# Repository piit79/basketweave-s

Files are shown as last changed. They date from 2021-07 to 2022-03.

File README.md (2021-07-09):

# Basketweave-S

Through-hole Alice-style keyboard with arrow keys, symmetric 3-key macro clusters, and a rotary encoder

Based on the [Basketweave](https://github.com/null-l/basketweave) by [null-l](https://github.com/null-l)

### Default Layout
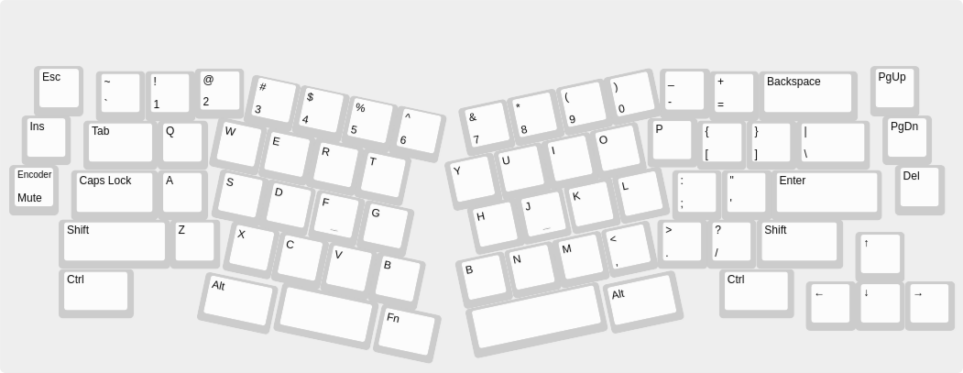
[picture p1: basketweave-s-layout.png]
Default Layout

> View on [Keyboard Layout Editor](http://www.keyboard-layout-editor.com/#/gists/975ace00974ba7fb16d758d6a68e5321)

### BOM and Build Guide
[Build Guide](doc/build.md)

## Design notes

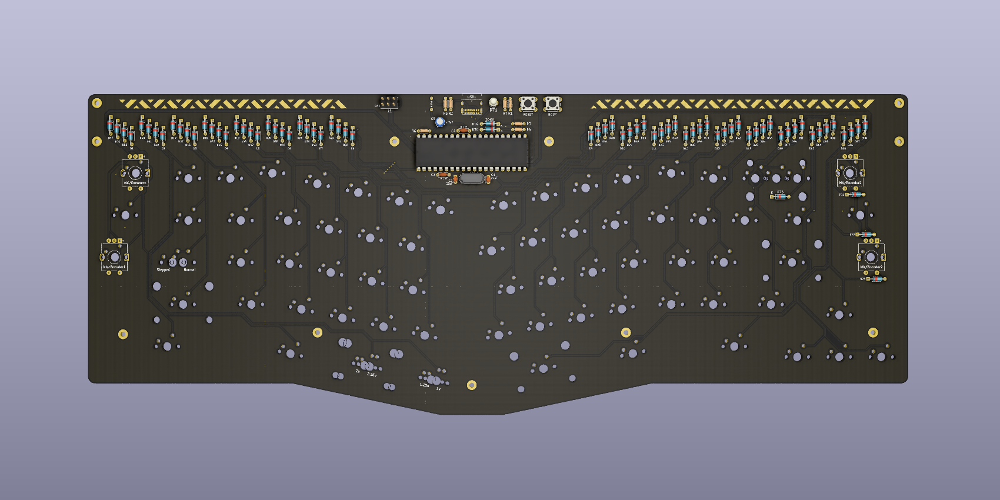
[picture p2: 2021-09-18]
basketweave/basketweave-s-1.9-pcb.png

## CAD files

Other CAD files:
basketweave/basketweave-acrylic-cover.dxf

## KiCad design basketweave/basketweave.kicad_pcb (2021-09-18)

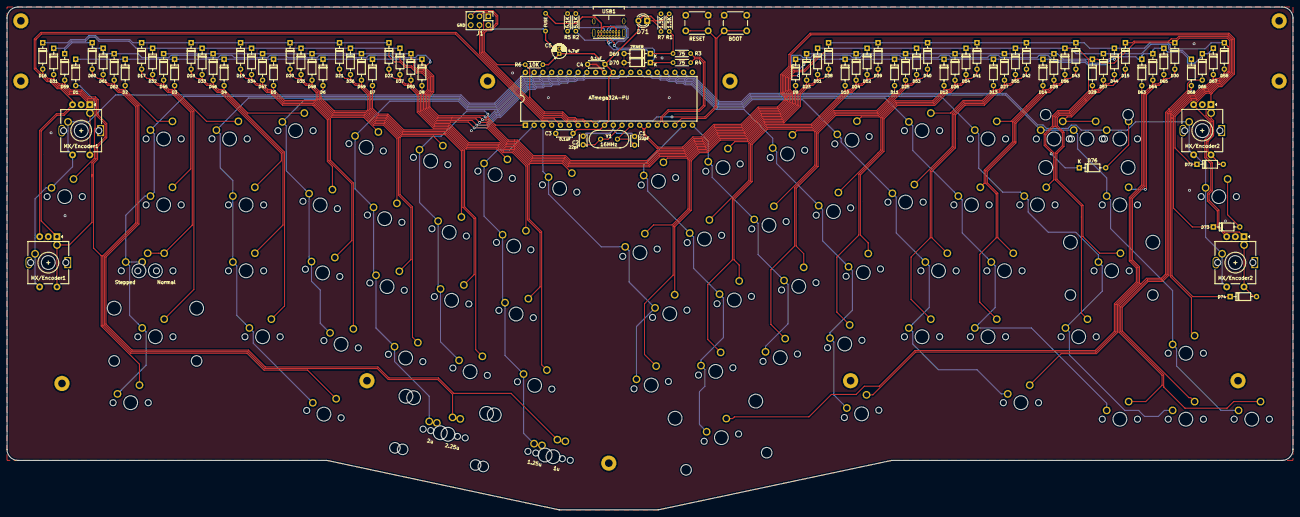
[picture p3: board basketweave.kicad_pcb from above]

Board: 2 copper layers, 371.5 x 145.3 mm, 187 parts (0 on the bottom side), 114 nets.

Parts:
C1, C2: 22pF; C_Disc_D3.0mm_W2.0mm_P2.50mm
C3, C4: 0.1uF; C_Disc_D4.3mm_W1.9mm_P5.00mm
C5: 4.7uF; CP_Radial_D4.0mm_P1.50mm
D1, D2, D3, D4, D5, D6, D7, D8, D9, D10, D11, D12, D13, D14, D15, D16, D17, D18, D19, D20, D21, D22, D23, D24, D25, D26, D27, D28, D29, D30, D31, D32, D33, D34, D35, D36, D37, D38, D39, D40, D41, D42, D43, D44, D45, D46, D47, D48, D49, D50, D51, D52, D53, D54, D55, D56, D57, D58, D59, D60, D61, D62, D63, D64, D65, D66, D67, D68, D72, D73, D74, D76: D_Small; D_DO-35_SOD27_P7.62mm_Horizontal
D69, D70: 3.6V; D_DO-35_SOD27_P7.62mm_Horizontal
D71: LED; LED_D3.0mm_Clear
F1: 500mA; polyfuse_5.1mm
H1, H2, H3, H4, H5, H6, H7, H8, H9, H11, H13: MountingHole; MountingHole_2.2mm_M2_Pad
J1: AVR-ISP-6; PinHeader_2x03_P2.54mm_Vertical
MX1, MX2, MX3, MX4, MX5, MX6, MX7, MX8, MX9, MX10, MX11, MX12, MX13, MX14, MX16, MX18, MX19, MX20, MX21, MX22, MX23, MX24, MX25, MX26, MX27, MX28, MX29, MX31, MX34, MX35, MX36, MX37, MX38, MX39, MX40, MX41, MX42, MX43, MX44, MX47, MX48, MX49, MX50, MX51, MX52, MX53, MX54, MX55, MX56, MX57, MX59, MX67, MX68, MX69, MX71, MX72, MX73, MX74, MX75, MX76: MX-NoLED; MXOnly-1U-NoLED
MX15: MX-NoLED; MXOnly-2U-NoLED
MX17, MX30, MX60, MX61, MX65, MX66: MX-NoLED; MXOnly-1.5U-NoLED
MX32, MX63: MX-NoLED; MXOnly-1.25U-NoLED
MX33, MX58: MX-NoLED; MXOnly-1.75U-NoLED
MX45, MX46, MX70: MX-NoLED; MXOnly-2.25U-ReversedStabilizers-NoLED
MX62: MX-NoLED; MXOnly-2U-ReversedStabilizers-NoLED
MX64: MX-NoLED; MXOnly-2.75U-ReversedStabilizers-NoLED
PATTERN1: Pattern_Left; pattern_left
PATTERN2: Pattern_Right; pattern_right
R1, R7: 1.5K; R_Axial_DIN0204_L3.6mm_D1.6mm_P5.08mm_Horizontal
R2, R5: 5.1K; R_Axial_DIN0204_L3.6mm_D1.6mm_P5.08mm_Horizontal
R3, R4: 75; R_Axial_DIN0204_L3.6mm_D1.6mm_P5.08mm_Horizontal
R6: 10K; R_Axial_DIN0204_L3.6mm_D1.6mm_P5.08mm_Horizontal
SW1: BOOT; SW_PUSH_6mm
SW2: RESET; SW_PUSH_6mm
SW3, SW4, SW5, SW6: Rotary_Encoder_Switch; RotaryEncoder_Alps_EC11E-Switch_Vertical_H20mm-for-MX
U1: ATmega32A-PU; DIP-40_W15.24mm
USB1: GCT-USB-4085-GF-A; USB_C_GCT_USB4085
Y1: 16Mhz; Crystal_HC49-4H_Vertical

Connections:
+5V: C3.1, C4.1, C5.1, D71.2, F1.1, J1.2, R1.1, R6.1, U1.10, U1.30
COL0: MX1.1, MX16.1, MX75.1, SW3.S1, SW5.S1, U1.40
COL1: MX2.1, MX17.1, MX32.1, MX33.1, MX46.1, MX60.1, U1.39
COL2: MX3.1, MX18.1, MX34.1, MX47.1, MX61.1, U1.38
COL3: MX4.1, MX19.1, MX35.1, MX48.1, U1.37
COL4: MX5.1, MX20.1, MX36.1, MX49.1, MX62.1, MX70.1, U1.36
COL5: MX6.1, MX21.1, MX37.1, MX50.1, U1.1
COL6: MX7.1, MX22.1, MX38.1, MX51.1, MX63.1, MX71.1, U1.2
COL7: MX8.1, MX23.1, MX39.1, MX52.1, U1.3
COL8: MX9.1, MX24.1, MX40.1, MX53.1, MX64.1, U1.19
COL9: MX10.1, MX25.1, MX41.1, MX54.1, U1.20
COL10: MX11.1, MX26.1, MX42.1, MX55.1, MX65.1, U1.27
COL11: MX12.1, MX27.1, MX43.1, MX56.1, MX66.1, U1.26
COL12: MX13.1, MX28.1, MX44.1, MX57.1, MX67.1, U1.25
COL13: MX14.1, MX29.1, MX45.1, MX58.1, MX68.1, U1.24
COL14: MX15.1, MX30.1, MX31.1, MX59.1, MX69.1, U1.23
COL15: MX72.1, MX73.1, MX74.1, MX76.1, SW4.S1, SW6.S1, U1.22
D+: R4.1, U1.16
D-: R3.1, U1.17
EN_A1: SW3.A, SW5.A, U1.4
EN_A2: SW3.B, SW5.B, U1.5
EN_B1: SW4.A, SW6.A, U1.15
EN_B2: SW4.B, SW6.B, U1.14
GND: C1.1, C2.1, C3.2, C4.2, C5.2, D69.2, D70.2, J1.6, R2.1, R5.1, R7.2, SW1.1, SW2.1, SW3.C, SW4.C, SW5.C, SW6.C, U1.11, U1.31, USB1.A1, USB1.A12, USB1.B1, USB1.B12, USB1.S1
MISO: J1.1, U1.7
MOSI: J1.4, U1.6
unnamed: C1.2, U1.13, Y1.1
unnamed: C2.2, U1.12, Y1.2
unnamed: D1.2, MX1.2, SW5.S2
unnamed: D2.2, MX2.2
unnamed: D3.2, MX3.2
unnamed: D4.2, MX4.2
unnamed: D5.2, MX5.2
unnamed: D6.2, MX6.2
unnamed: D7.2, MX7.2
unnamed: D8.2, MX8.2
unnamed: D9.2, MX9.2
unnamed: D10.2, MX10.2
unnamed: D11.2, MX11.2
unnamed: D12.2, MX12.2
unnamed: D13.2, MX13.2
unnamed: D14.2, MX14.2
unnamed: D15.2, MX15.2, MX31.2
unnamed: D16.2, MX16.2
unnamed: D17.2, MX17.2
unnamed: D18.2, MX18.2
unnamed: D19.2, MX19.2
unnamed: D20.2, MX20.2
unnamed: D21.2, MX21.2
unnamed: D22.2, MX22.2
unnamed: D23.2, MX23.2
unnamed: D24.2, MX24.2
unnamed: D25.2, MX25.2
unnamed: D26.2, MX26.2
unnamed: D27.2, MX27.2
unnamed: D28.2, MX28.2
unnamed: D29.2, MX29.2
unnamed: D30.2, MX30.2
unnamed: D31.2, MX75.2, SW3.S2
unnamed: D32.2, MX32.2, MX33.2
unnamed: D33.2, MX34.2
unnamed: D34.2, MX35.2
unnamed: D35.2, MX36.2
unnamed: D36.2, MX37.2
unnamed: D37.2, MX38.2
unnamed: D38.2, MX39.2
unnamed: D39.2, MX40.2
unnamed: D40.2, MX41.2
unnamed: D41.2, MX42.2
unnamed: D42.2, MX43.2
unnamed: D43.2, MX44.2
unnamed: D44.2, MX45.2
unnamed: D45.2, MX46.2
unnamed: D46.2, MX47.2
unnamed: D47.2, MX48.2
unnamed: D48.2, MX49.2
unnamed: D49.2, MX50.2
unnamed: D50.2, MX51.2
unnamed: D51.2, MX52.2
unnamed: D52.2, MX53.2
unnamed: D53.2, MX54.2
unnamed: D54.2, MX55.2
unnamed: D55.2, MX56.2
unnamed: D56.2, MX57.2
unnamed: D57.2, MX58.2
unnamed: D58.2, MX59.2
unnamed: D59.2, MX60.2
unnamed: D60.2, MX61.2
unnamed: D61.2, MX62.2, MX70.2
unnamed: D62.2, MX63.2, MX71.2
unnamed: D63.2, MX64.2
unnamed: D64.2, MX65.2
unnamed: D65.2, MX66.2
unnamed: D66.2, MX67.2
unnamed: D67.2, MX68.2
unnamed: D68.2, MX69.2
unnamed: D69.1, R1.2, R3.2, USB1.A7, USB1.B7
unnamed: D70.1, R4.2, USB1.A6, USB1.B6
unnamed: D71.1, R7.1
unnamed: D72.2, MX72.2, SW6.S2
unnamed: D73.2, MX73.2
unnamed: D74.2, MX74.2, SW4.S2
unnamed: D76.2, MX76.2
unnamed: R2.2, USB1.A5
unnamed: R5.2, USB1.B5
ROW0: D1.1, D2.1, D3.1, D4.1, D5.1, D6.1, D7.1, D8.1, D9.1, D10.1, D11.1, D12.1, D13.1, D14.1, D15.1, D72.1, U1.34
ROW1: D16.1, D17.1, D18.1, D19.1, D20.1, D21.1, D22.1, D23.1, D24.1, D25.1, D26.1, D27.1, D28.1, D29.1, D30.1, D73.1, U1.28
ROW2: D31.1, D32.1, D33.1, D34.1, D35.1, D36.1, D37.1, D38.1, D39.1, D40.1, D41.1, D42.1, D43.1, D44.1, D58.1, D74.1, U1.29
ROW3: D45.1, D46.1, D47.1, D48.1, D49.1, D50.1, D51.1, D52.1, D53.1, D54.1, D55.1, D56.1, D57.1, D68.1, D76.1, U1.33
ROW4: D59.1, D60.1, D61.1, D62.1, D63.1, D64.1, D65.1, D66.1, D67.1, U1.35
SCK: J1.3, U1.8
VCC: F1.2, USB1.A4, USB1.A9, USB1.B4, USB1.B9
boot: SW1.2, U1.18
reset: J1.5, R6.2, SW2.2, U1.9

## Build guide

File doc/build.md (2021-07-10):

# Build Guide

## Required Components
You will need the following tools and components to build the Basketweave-S (not included in the kit):
- Soldering iron and solder
- Phillips head screwdriver
- Flush side cutters
- No-clean flux (recommended to prevent bridging on USB pins)
- 70 MX style switches (or 71 when not using the encoder)
- 5 PCB mount 2u stabilizers
- Keycaps (check compatibility, this layout uses many non-standard keys)
- USB Type C cable
## Included Components
The following components are included in the Basketweave keyboard kit:
kit
| Ref | Component | Qty | Notes |
| --- | --- | --- | ----- |
| C1, C2  | 22pF Capacitor | 2
| C3, C4  | 0.1uF Capacitor | 2
| C5 | 4.7uF Capacitor | 1
| D1-68, D71-74 | 1n4148 Diode | 71
| D69, D70 | 3.6V Zener Diode | 2  | Keep separate from the 1n4148 diodes
| FUSE | 500mA Resettable fuse  | 1
| ISP | 6 pin header | 1
| USB | GCT USB4085 USB-C port | 1
| POWER | 3mm LED | 1
| R1, R7  | 1.5k Resistor | 2
| R2, R5  | 5.1k Resistor | 2
| R3, R4  | 75R Resistor | 2
| R6 | 10k Resistor | 1
| U1 | ATmega32A-PU | 1
| | 40 pin IC socket | 1
| RESET, BOOT | 6mm push button | 1
| Y1 | 16MHz Crystal | 1
| | EC11 Rotary encoder | 1
| | Knob | 1
| | M2 6mm standoff | 11
| | M2 10+3mm standoff | 6
| | M2 6mm screw | 6
| | M2 4mm screw | 16
| | Rubber Feet | 4
| | Basketweave-S PCB | 1
| | Bottom plate | 1
| | Switch plate | 1

### Step 1. Zener Diodes (D69, D70)
**This part has specific orientation** - black line on the diode lines up with the square pad (points left)
Zener Diodes

### Step 2. Resistors (R1-7)
Orientation does not matter. Solder based on the labeled values.
| Ref | Value |
| --- | ----- |
| R1, R7 | 1.5k  |
| R2, R5 | 5.1k  |
| R3, R4 | 75 |
| R6 | 10k |
Resistors

### Step 3. 1n1418 Diodes (D1-68, D71-74)
**This part has a specific orientation** - black line on the diode lines up with the square pad (points up)
Diodes

### Step 4. Capacitors (C1-4)
Orientation does not matter. Solder based on the labeled values.
| Ref | Value |
| --- | ----- |
| C1, C2 | 22uF  |
| C3, C4 | 0.1uF |
Capacitors

### Step 5. USB Port
Solder one of the large legs first and check that the port is flush before soldering the other three legs. \
Solder the smaller pins by applying no-clean flux across the pins, then drag a small amount of solder across the pins until all the holes are filled.
USB port

### Step 6. Capacitor (C5)
**This part has a specific orientation** - longer leg goes in square pad (white mark on the capacitor points up)
Capacitor

### Step 7. Fuse
Orientation does not matter. Fold down after soldering.
Fuse

### Step 8. Crystal (Y1)
Orientation does not matter.
Crystal

### Step 9. LED
**This part has a specific orientation** - shorter leg and flat side of the LED line up with the square pad
LED

### Step 10. Push Button (RESET, BOOT) and IC Socket
Push buttons have no specific orientation. \
Align the notch on the IC Socket with the markings on the PCB. 
Push button and IC socket

### Step 11. Pin Header
Orientation does not matter. 
Pin header

### Step 12. ATmega32A
Insert ATmega32A into the IC socket. Make sure the notch on the microcontroller aligns with the notch in the IC socket and the markings on the PCB.

### Step 13. M2 6mm Standoffs, M2 10+3mm Standoffs, M2 4mm screws
| Component | Qty | Location |
| --- | --- | --- |
| M2 10+3mm standoff | 6 | Front top |
| M2 4mm screws | 5 | Front bottom |
| M2 6mm standoff | 11  | Back |
Screws

### Step 14. Switches and Rotary Encoder
Install the stabilizers, then place the plate on top. \
Install and solder switches and rotary encoder.
Switches

### Step 15. Bottom Plate
(optional) Flip the board over and insert foam. Screw angling feet into the bottom plate. \
Screw in bottom plate using 11x M2 4mm screws. \
Attach rubber feet.
Foam
Bottom plate

### Step 16. Acrylic Guard
Screw in acrylic guard using 6x M2 6mm screws. Be careful not to overtighten.
Acrylic

### Step 17. Keycaps
Add keycaps.
Keycaps

Done!

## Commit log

2021-01-29 Remove and ignore sch/pcb backup files
2021-01-29 Move macro keys to the right and encoder to the left
    [basketweave.kicad_pcb, basketweave.sch, basketweave_plate.kicad_pcb]
2021-02-22 Make macro keys symmetric on both sides; move encoder to the left
    [basketweave.kicad_pcb, basketweave.sch, basketweave_plate.kicad_pcb]
2021-02-22 Replace gerbers with JLCPCB-friendly ones; add gerber zips
    [basketweave-B_Cu.gbr, basketweave-B_Mask.gbr, basketweave-B_Paste.gbr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]
2021-07-10 Replace the acrylic cover file
    [acrylic_guard.dxf, basketweave-acrylic-cover.dxf]
2021-07-10 Add back PCB patterns above diodes
    [basketweave.kicad_pcb, basketweave.sch]
2021-07-10 Add second rotary encoder on the right
    [basketweave.kicad_pcb, basketweave.sch]
2021-07-10 Change encoder plate cutout to standard MX one
    [basketweave_plate.kicad_pcb]
2021-07-10 Add footprint library for the bottom plate
2021-07-10 Update gerbers
    [basketweave-B_Cu.gbr, basketweave-B_Mask.gbr, basketweave-B_Paste.gbr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]
2021-09-17 Add support for encoders in the top macro positions
    [basketweave.kicad_pcb, basketweave.sch]
2021-09-17 Modify plate logo for Basketweave-S and move it into PCB footprint library
    [basketweave_plate.kicad_pcb]
2021-09-17 Modify bottom plate logo for Basketweave-S and move it into PCB footprint library
    [basketweave_bottom.kicad_pcb]
2021-09-18 Add support for split backspace
    [basketweave.kicad_pcb, basketweave.sch, basketweave_plate.kicad_pcb]
2022-03-16 Enlarge right space cutout; fix position according to PCB
    [basketweave_plate-B_Cu.gbl, basketweave_plate-B_Silkscreen.gbo, basketweave_plate-Edge_Cuts.gm1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]
